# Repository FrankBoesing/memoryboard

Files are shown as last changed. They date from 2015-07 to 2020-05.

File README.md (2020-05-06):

# Memoryboard for Teensy 3.x

1..6x spi jedec-memory soic-8 (e.g. 23LC1024 RAM)

Top
Bottom

Partslist:

- 6 x SPI jedec Memory of your choice* (SOIC-8) (RAM (e.g. 23LC1024) , Flash...)
- 1 x 74LCX126MX SOIC-14
- 1 x 74LCX138MX SOIC-16
- 6 x Capacitor 0.1uF 0603
- 3 x Resistor 10K 0603

*Check package-width!

https://forum.pjrc.com/threads/29276-Limits-of-delay-effect-in-audio-library
(up to 9 sec. delay for audio 44kHz)

Of course, this board is not only for the audio-library! 

OSH-Park shared project:
https://oshpark.com/shared_projects/KZt5PaU7

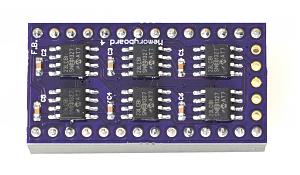
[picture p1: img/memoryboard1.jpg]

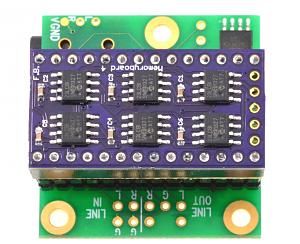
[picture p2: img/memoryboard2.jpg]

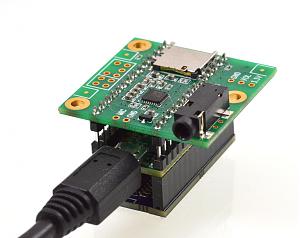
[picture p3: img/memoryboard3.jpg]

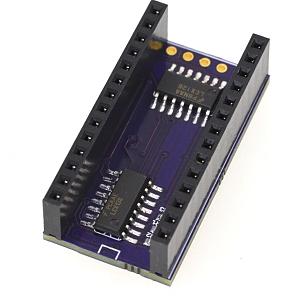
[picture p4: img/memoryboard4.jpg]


Video of delay effect:
video (https://www.youtube.com/watch?v=d80d1HWy5_s)

Pins used:
- 3v3, 
- GND, 
- 2,3,4 (Chipselects) 
- 7, 12, 14 (SPI)

### License

<br />This work is licensed under a <a rel="license" href="http://creativecommons.org/licenses/by-sa/4.0/">Creative Commons Attribution-ShareAlike 4.0 International License</a>.

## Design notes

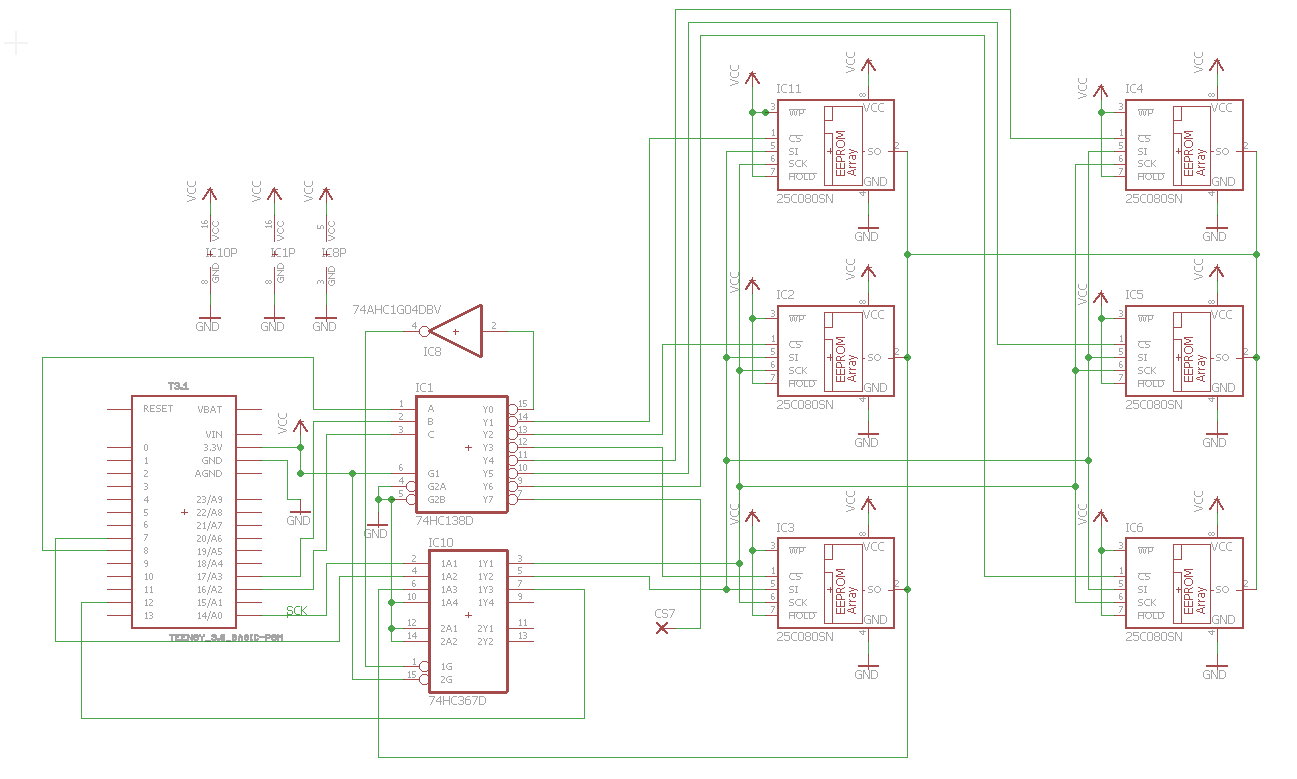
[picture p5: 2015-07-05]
memoryboard-schematic.png

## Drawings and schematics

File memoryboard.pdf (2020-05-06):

# SPI Memory VCC

# SPI Memory VCC

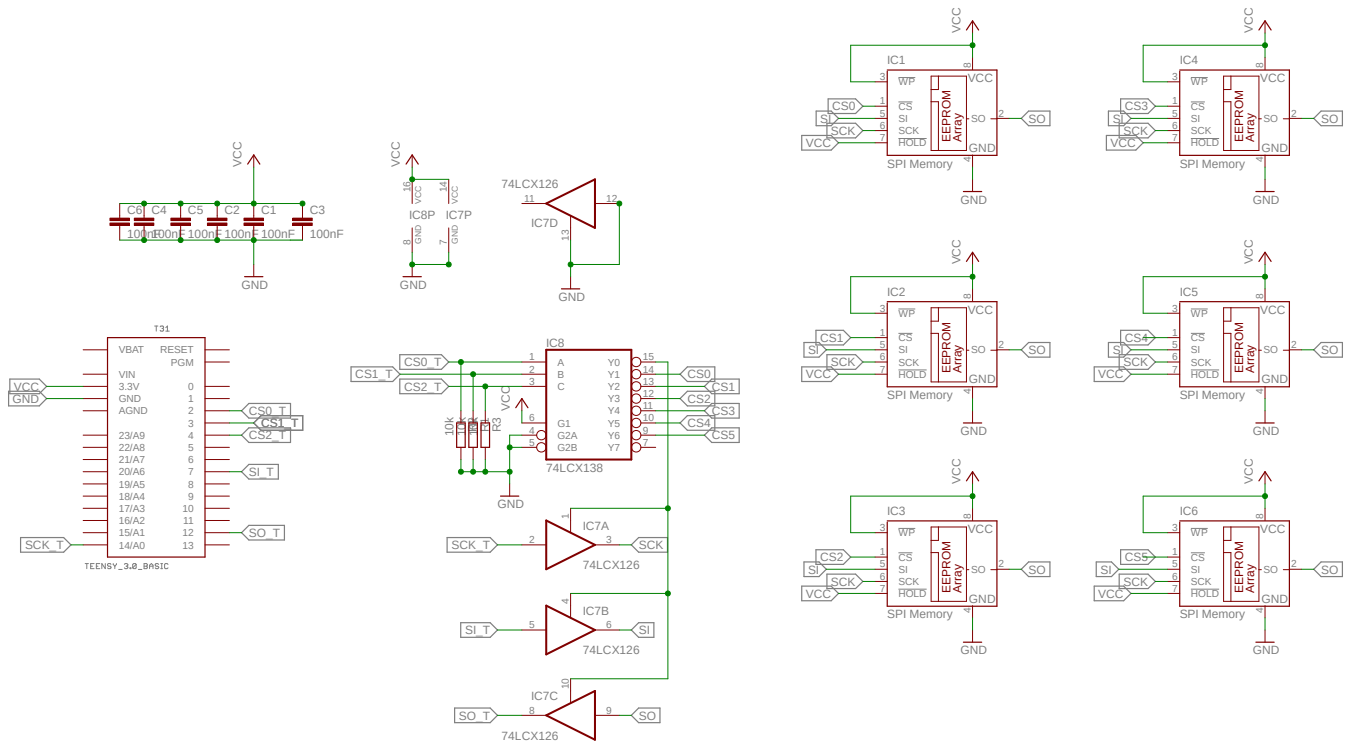
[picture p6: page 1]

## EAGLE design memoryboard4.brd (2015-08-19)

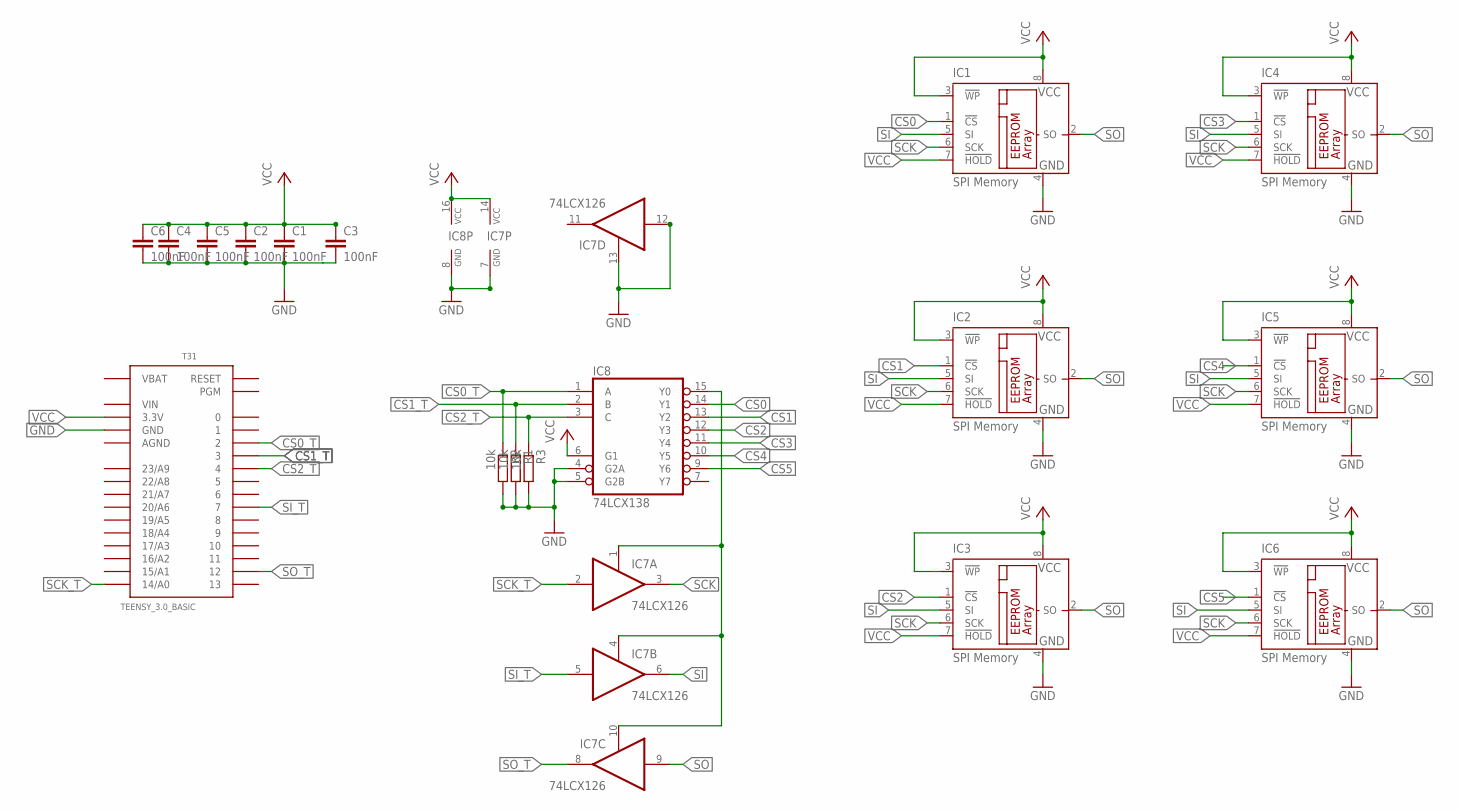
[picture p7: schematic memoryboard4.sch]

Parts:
C1, C2, C3, C4, C5, C6: 100nF; C0603
IC1, IC2, IC3, IC4, IC5, IC6: SPI Memory; SO-08
IC7: 74LCX126; SO14
IC8: 74LCX138; SO16
R1, R2, R3: 10k; R0603
T31: TEENSY_3.0_BASIC

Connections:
AGND: T31.AGND
CS0: IC1.1 (!CS), IC8.14 (Y1)
CS0_T: IC8.1 (A), R2.1, T31.2
CS1: IC2.1 (!CS), IC8.13 (Y2)
CS1_T: IC8.2 (B), R1.1, T31.3
CS2: IC3.1 (!CS), IC8.12 (Y3)
CS2_T: IC8.3 (C), R3.1, T31.4
CS3: IC4.1 (!CS), IC8.11 (Y4)
CS4: IC5.1 (!CS), IC8.10 (Y5)
CS5: IC6.1 (!CS), IC8.9 (Y6)
GND: C1.2, C2.2, C3.2, C4.2, C5.2, C6.2, IC1.4 (GND), IC2.4 (GND), IC3.4 (GND), IC4.4 (GND), IC5.4 (GND), IC6.4 (GND), IC7.7 (GND), IC7.12 (I), IC7.13 (OE), IC8.4 (G2A), IC8.5 (G2B), IC8.8 (GND), R1.2, R2.2, R3.2, T31.GND, T31.GND1 (GND)
SCK: IC1.6 (SCK), IC2.6 (SCK), IC3.6 (SCK), IC4.6 (SCK), IC5.6 (SCK), IC6.6 (SCK), IC7.3 (O)
SCK_T: IC7.2 (I), T31.14/A0
SI: IC1.5 (SI), IC2.5 (SI), IC3.5 (SI), IC4.5 (SI), IC5.5 (SI), IC6.5 (SI), IC7.6 (O)
SI_T: IC7.5 (I), T31.7
SO: IC1.2 (SO), IC2.2 (SO), IC3.2 (SO), IC4.2 (SO), IC5.2 (SO), IC6.2 (SO), IC7.9 (I)
SO_T: IC7.8 (O), T31.12
SPI_ENABLE: IC7.1 (OE), IC7.4 (OE), IC7.10 (OE), IC8.15 (Y0)
VBAT: T31.VBAT
VCC: C1.1, C2.1, C3.1, C4.1, C5.1, C6.1, IC1.3 (!WP), IC1.7 (!HOLD), IC1.8 (VCC), IC2.3 (!WP), IC2.7 (!HOLD), IC2.8 (VCC), IC3.3 (!WP), IC3.7 (!HOLD), IC3.8 (VCC), IC4.3 (!WP), IC4.7 (!HOLD), IC4.8 (VCC), IC5.3 (!WP), IC5.7 (!HOLD), IC5.8 (VCC), IC6.3 (!WP), IC6.7 (!HOLD), IC6.8 (VCC), IC7.14 (VCC), IC8.6 (G1), IC8.16 (VCC), T31.3.3V, T31.3.3V1 (3.3V)
VIN: T31.VIN

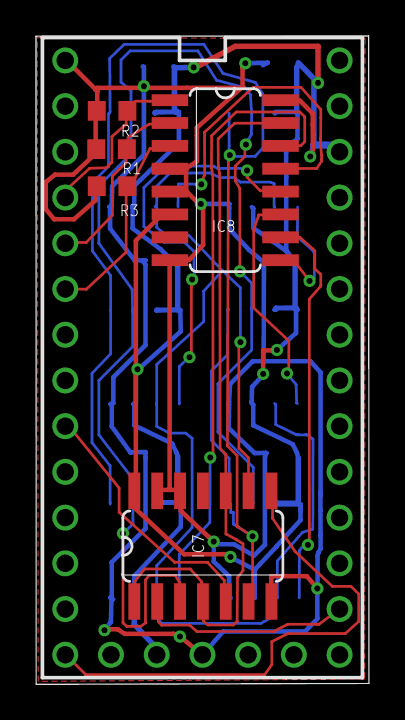
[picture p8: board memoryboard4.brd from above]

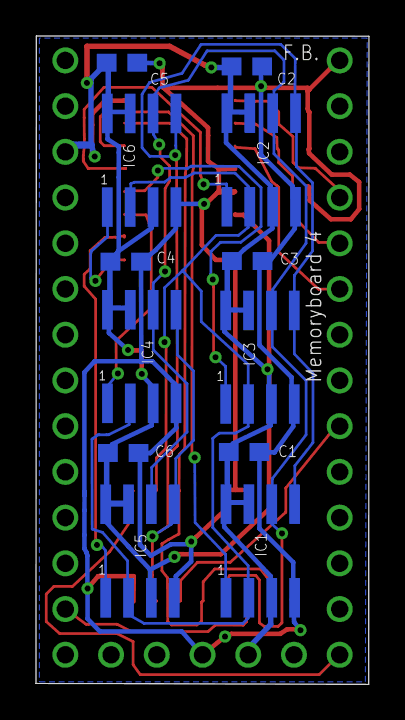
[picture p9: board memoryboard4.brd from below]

Board: 2 copper layers, 18.5 x 36.0 mm, 18 parts (12 on the bottom side), 18 nets.

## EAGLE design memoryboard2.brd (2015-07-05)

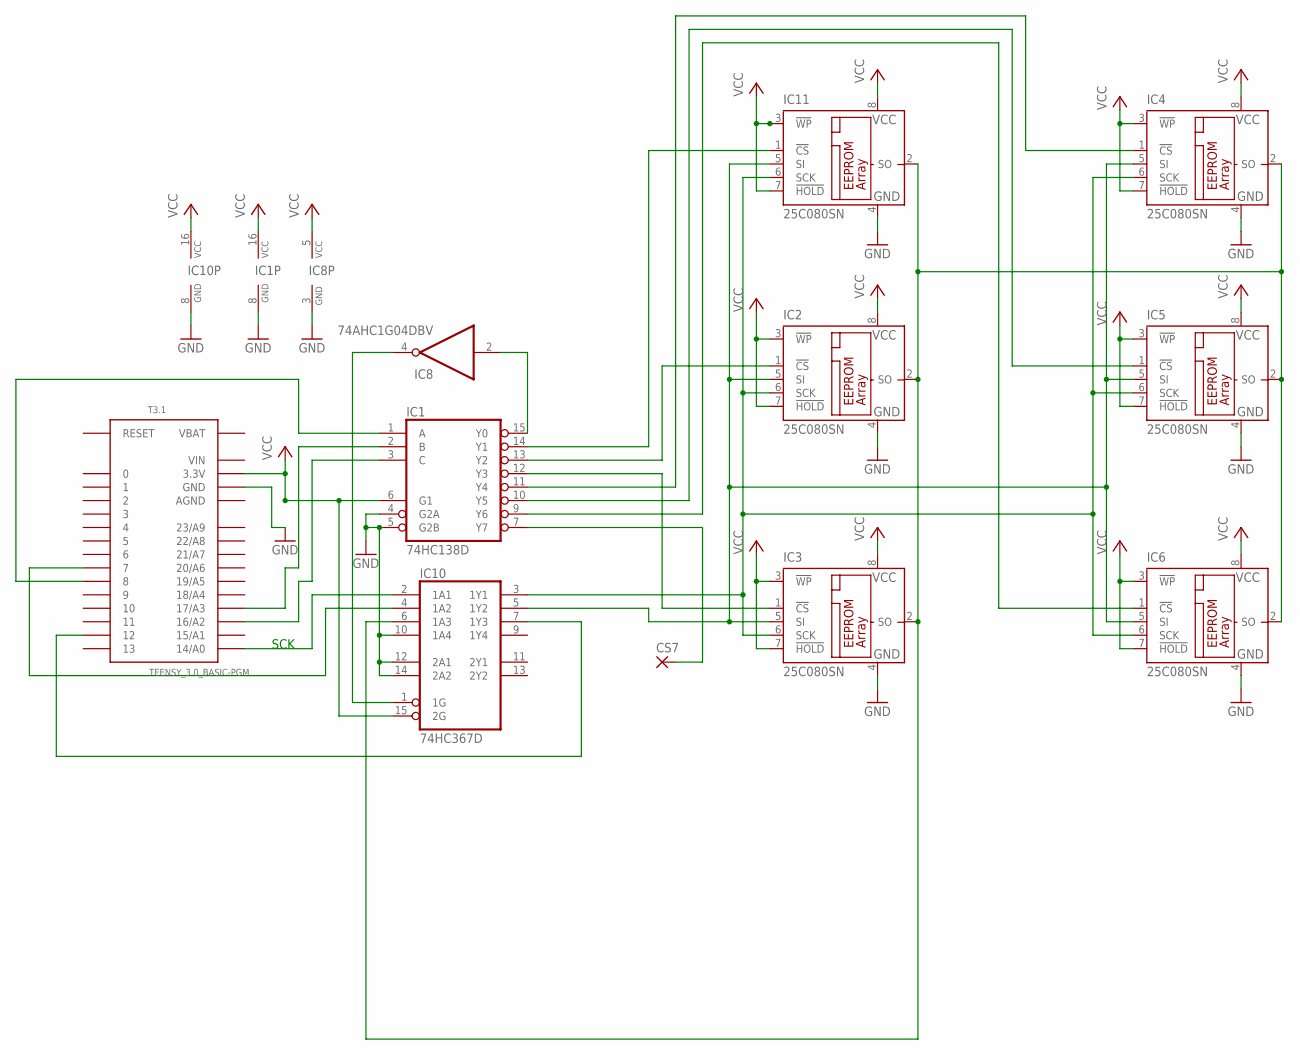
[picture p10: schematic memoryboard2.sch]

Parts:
CS7: SMD2; SMD1,27-2,54
IC1: 74HC138D; SO16
IC2, IC3, IC4, IC5, IC6, IC11: 25C080SN; SO-08
IC8: 74AHC1G04DBV; SOT23-5
IC10: 74HC367D; SO16
T3.1: TEENSY_3.0_BASIC-PGM

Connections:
AGND: T3.1.AGND
GND: IC1.4 (G2A), IC1.5 (G2B), IC1.8 (GND), IC2.4 (GND), IC3.4 (GND), IC4.4 (GND), IC5.4 (GND), IC6.4 (GND), IC8.3 (GND), IC10.8 (GND), IC10.10 (1A4), IC10.12 (2A1), IC10.14 (2A2), IC11.4 (GND), T3.1.GND, T3.1.GND1 (GND)
unnamed: IC8.4 (O), IC10.1 (1G)
unnamed: IC10.2 (1A1), T3.1.14/A0
unnamed: IC10.4 (1A2), T3.1.7
unnamed: IC10.7 (1Y3), T3.1.12
unnamed: IC1.15 (Y0), IC8.2 (I)
unnamed: IC1.3 (C), T3.1.16/A2
unnamed: CS7.1, IC1.7 (Y7)
unnamed: IC1.10 (Y5), IC5.1 (!CS)
unnamed: IC2.6 (SCK), IC3.6 (SCK), IC4.6 (SCK), IC5.6 (SCK), IC6.6 (SCK), IC10.3 (1Y1), IC11.6 (SCK)
unnamed: IC1.2 (B), T3.1.17/A3
unnamed: IC1.9 (Y6), IC6.1 (!CS)
unnamed: IC1.12 (Y3), IC3.1 (!CS)
unnamed: IC2.2 (SO), IC3.2 (SO), IC4.2 (SO), IC5.2 (SO), IC6.2 (SO), IC10.6 (1A3), IC11.2 (SO)
unnamed: IC1.11 (Y4), IC4.1 (!CS)
unnamed: IC1.1 (A), T3.1.8
unnamed: IC2.5 (SI), IC3.5 (SI), IC4.5 (SI), IC5.5 (SI), IC6.5 (SI), IC10.5 (1Y2), IC11.5 (SI)
unnamed: IC1.14 (Y1), IC11.1 (!CS)
unnamed: IC1.13 (Y2), IC2.1 (!CS)
VBAT: T3.1.VBAT
VCC: IC1.6 (G1), IC1.16 (VCC), IC2.3 (!WP), IC2.7 (!HOLD), IC2.8 (VCC), IC3.3 (!WP), IC3.7 (!HOLD), IC3.8 (VCC), IC4.3 (!WP), IC4.7 (!HOLD), IC4.8 (VCC), IC5.3 (!WP), IC5.7 (!HOLD), IC5.8 (VCC), IC6.3 (!WP), IC6.7 (!HOLD), IC6.8 (VCC), IC8.5 (VCC), IC10.15 (2G), IC10.16 (VCC), IC11.3 (!WP), IC11.7 (!HOLD), IC11.8 (VCC), T3.1.3.3V, T3.1.3.3V1 (3.3V)
VIN: T3.1.VIN

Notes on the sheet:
SCK

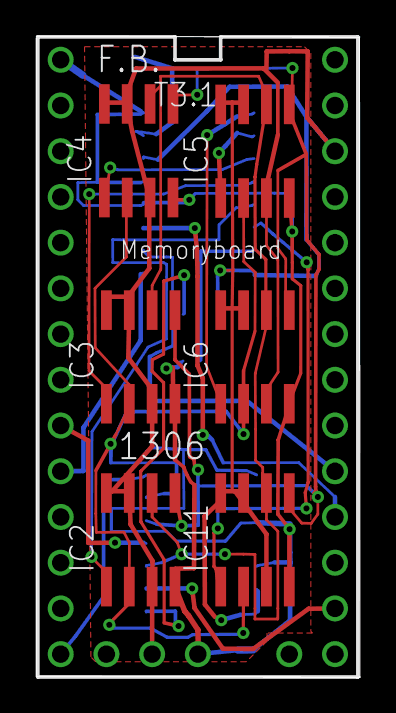
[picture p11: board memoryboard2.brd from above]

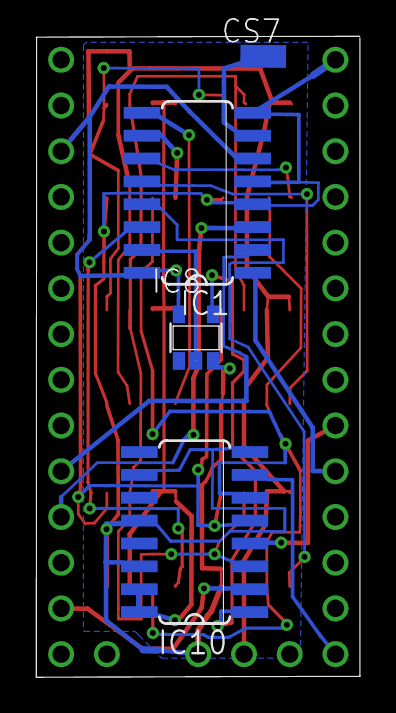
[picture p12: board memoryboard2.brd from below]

Board: 2 copper layers, 18.0 x 35.6 mm, 11 parts (4 on the bottom side), 20 nets.

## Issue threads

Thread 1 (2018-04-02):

OK to swap the 100nF caps for 4.7uF?

dturner, 2018-04-02:
Hi Frank. Thanks for sharing this awesome little board design. A quick question if you don't mind. I accidentally used 4.7uF capacitors instead of 100nF. The test script runs successfully but I'm wondering whether I should swap them for 100nF?

FrankBoesing, 2018-04-02:
Hi Don, the capacitors are meant as blocking caps for the RAMs- their value is not that important I think - but 4.7uF is really a lot more than in the datasheet. On the other hand, if it works...

dturner, 2018-04-02:
OK thanks Frank, I'll leave as is. If the RAM chips blow up I'll update this ticket :)

Closed 2018-04-02.

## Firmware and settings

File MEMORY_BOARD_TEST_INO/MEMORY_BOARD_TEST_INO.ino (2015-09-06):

/* Memoryboard code is placed under the MIT license
 * Copyright (c) 2015 Frank Bösing
 *
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
 * THE SOFTWARE IS PROVIDED "AS IS", WITHOUT WARRANTY OF ANY KIND,
 * EXPRESS OR IMPLIED, INCLUDING BUT NOT LIMITED TO THE WARRANTIES OF
 * MERCHANTABILITY, FITNESS FOR A PARTICULAR PURPOSE AND
 * NONINFRINGEMENT. IN NO EVENT SHALL THE AUTHORS OR COPYRIGHT HOLDERS
 * BE LIABLE FOR ANY CLAIM, DAMAGES OR OTHER LIABILITY, WHETHER IN AN
 * ACTION OF CONTRACT, TORT OR OTHERWISE, ARISING FROM, OUT OF OR IN
 * CONNECTION WITH THE SOFTWARE OR THE USE OR OTHER DEALINGS IN THE
 * SOFTWARE.
 */

 #include <SPI.h>
#include <SPIFIFO.h>
#include <arm_math.h>
#include <kinetis.h>
#include "memoryboard.h"


#define BUFSIZE 8000
#define BUFSIZE3 1024

DMAMEM uint8_t buf1[BUFSIZE];
DMAMEM uint8_t buf2[BUFSIZE];
DMAMEM uint16_t buf3[BUFSIZE3];

uint32_t laufnr;


void setup() {
 memoryboard_init();
 while(!Serial);
 Serial.println("Start");
 laufnr = 0;
}


void checkMem(int num){
int m,res;
uint32_t addr;

  Serial.printf("RAM #%d ... ", num);
  m = millis();
  res = 0;
  if (ram_readRDMR(num) != 0x40) {
	  res = 1;
  }
  for (addr = 0; addr < 128*1024; addr += BUFSIZE) {
  //for (addr = 0; addr < BUFSIZE; addr += BUFSIZE) {
  if (res == 0) {
    memset(buf1,0x55,BUFSIZE);
    ram_write(num, buf1, addr, BUFSIZE);
    ram_read(num, buf2, addr, BUFSIZE);
    res = memcmp(buf1,buf2,BUFSIZE);
  }
  if (res==0) {
    memset(buf1,0xaa,BUFSIZE);
    ram_write(num, buf1, addr, BUFSIZE);
    ram_read(num, buf2, addr, BUFSIZE);
    res = memcmp(buf1,buf2,BUFSIZE);
  }
  if (res==0) {
    memset(buf1,0x00,BUFSIZE);
    ram_write(num, buf1, addr, BUFSIZE);
    ram_read(num, buf2, addr, BUFSIZE);
    res = memcmp(buf1,buf2,BUFSIZE);
  }
/*
  if (res==0) {
    memset(buf1,0xff,BUFSIZE);
    ram_write(num, buf1, addr, BUFSIZE);
    ram_read(num, buf2, addr, BUFSIZE);
    res = memcmp(buf1,buf2,BUFSIZE);
  }
*/
  if (res==0) {
    int i;
    for (i=0; i< BUFSIZE3; i++)
      buf3[i] = i;
    ram_write(num, (uint8_t*)&buf3, addr, BUFSIZE);
    ram_read(num, buf2, addr, BUFSIZE3*2);
    res = memcmp(buf3,buf2,BUFSIZE3);
  }
  }
  m = millis()-m;
  Serial.printf("%s %ums\r\n",res==0?"OK":"ERROR",m);
  if (res) {
	Serial.printf("Stop.\r\nDump:\r\n");
	for (int i=0; i<BUFSIZE; i++)
		Serial.printf("0x%x<->0x%x\r\n", buf1[i], buf2[i]);
    while(1) {;}
  }

}


void loop() {
int num;
  laufnr++;
  Serial.printf("Run %u:\r\n", laufnr);

  for (num=1; num <=RAM_NUM_CHIPS; num++) checkMem(num);
  Serial.println();
  delay(300);
}

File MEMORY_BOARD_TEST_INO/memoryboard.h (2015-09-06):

/* Memoryboard library code is placed under the MIT license
 * Copyright (c) 2015 Frank Bösing
 *
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
 * THE SOFTWARE IS PROVIDED "AS IS", WITHOUT WARRANTY OF ANY KIND,
 * EXPRESS OR IMPLIED, INCLUDING BUT NOT LIMITED TO THE WARRANTIES OF
 * MERCHANTABILITY, FITNESS FOR A PARTICULAR PURPOSE AND
 * NONINFRINGEMENT. IN NO EVENT SHALL THE AUTHORS OR COPYRIGHT HOLDERS
 * BE LIABLE FOR ANY CLAIM, DAMAGES OR OTHER LIABILITY, WHETHER IN AN
 * ACTION OF CONTRACT, TORT OR OTHERWISE, ARISING FROM, OUT OF OR IN
 * CONNECTION WITH THE SOFTWARE OR THE USE OR OTHER DEALINGS IN THE
 * SOFTWARE.
 */

// Currently 23LC1024 SPI RAM only!

#ifndef _memoryboard_h
#define _memoryboard_h

/**************************/
// Edit here:

#define MEMORYBOARD_VERSION 3
#define RAM_NUM_CHIPS         (4) //# of RAMs

//End "Edit here"
/**************************/

#include <SPI.h>
//#include <SPIFIFO.h>
#include <DMAChannel.h>
#include <arm_math.h>

#if (MEMORYBOARD_VERSION < 4)
#define MEMORYBOARD_CS0     8
#define MEMORYBOARD_CS1    17
#define MEMORYBOARD_CS2    16
#elif (MEMORYBOARD_VERSION == 4)
#define MEMORYBOARD_CS0     2
#define MEMORYBOARD_CS1     3
#define MEMORYBOARD_CS2     4
#else
#error unknown MEMORYBOARD_VERSION
#endif

#define RAM_CHIP_SIZE         (128*1024) //Size per RAM
#define RAM_SIZE              (RAM_CHIP_SIZE * RAM_NUM_CHIPS)
#define RAM_CHIP_SIZE_MASK    (RAM_CHIP_SIZE - 1)
#define RAM_SIZE_MASK         (RAM_SIZE - 1)


#define MEMORYBOARD_SPICONFIG SPISettings(20000000, MSBFIRST, SPI_MODE0 ) //Speed. 23LC1024 = 20MHz max, see Datasheet.
#define MEMORYBOARD_SCK   	14
#define MEMORYBOARD_MOSI   	 7
#define MEMORYBOARD_MISO  	12

//RAM-Instructions
#define RAM_INSTR_READ      0x03
#define RAM_INSTR_WRITE     0x02
#define RAM_INSTR_EDIO      0x3B
#define RAM_INSTR_EQIO      0x38
#define RAM_INSTR_RSTIO     0xFF
#define RAM_INSTR_RDMR      0x05
#define RAM_INSTR_WRMR      0x01

#define RAM_BYTEMODE        0x00
#define RAM_PAGEMODE        0x80
#define RAM_SEQUENTIALMODE  0x40

#if (RAM_NUM_CHIPS < 0) || (RAM_NUM_CHIPS > 6)
#error please check RAM_NUM_CHIPS
#endif

#define MEMORYBOARD_PINMODE0	  pinMode(MEMORYBOARD_CS0, OUTPUT)
#define MEMORYBOARD_PINMODE1
#define MEMORYBOARD_PINMODE2
#define MEMORYBOARD_SETCS0(state) digitalWriteFast(MEMORYBOARD_CS0, state)
#define MEMORYBOARD_SETCS1(state)
#define MEMORYBOARD_SETCS2(state)
#if RAM_NUM_CHIPS > 1
#undef MEMORYBOARD_PINMODE1
#undef MEMORYBOARD_SETCS1
#define MEMORYBOARD_PINMODE1	  pinMode(MEMORYBOARD_CS1, OUTPUT)
#define MEMORYBOARD_SETCS1(state) digitalWriteFast(MEMORYBOARD_CS1, state)
#endif
#if RAM_NUM_CHIPS > 3
#undef MEMORYBOARD_PINMODE2
#undef MEMORYBOARD_SETCS2
#define MEMORYBOARD_PINMODE2	  {pinMode(MEMORYBOARD_CS2, OUTPUT);}
#define MEMORYBOARD_SETCS2(state) digitalWriteFast(MEMORYBOARD_CS2, state)
#endif

#define CSRELEASE				MEMORYBOARD_SETCS0(LOW);MEMORYBOARD_SETCS1(LOW);MEMORYBOARD_SETCS2(LOW)

static DMAChannel dmatx(true);
static DMAChannel dmarx(true);
static DMAMEM uint8_t dummy;
static volatile bool done;

static inline
void csassert(const int cs)
{
  switch(cs) {
    default:{ CSRELEASE;  break; }
    case 1: { MEMORYBOARD_SETCS0(HIGH); MEMORYBOARD_SETCS1(LOW);  MEMORYBOARD_SETCS2(LOW);  break; }
#if RAM_NUM_CHIPS > 1
    case 2: { MEMORYBOARD_SETCS0(LOW);  MEMORYBOARD_SETCS1(HIGH); MEMORYBOARD_SETCS2(LOW);  break; }
#if RAM_NUM_CHIPS > 2
    case 3: { MEMORYBOARD_SETCS0(HIGH); MEMORYBOARD_SETCS1(HIGH); MEMORYBOARD_SETCS2(LOW);  break; }
#if RAM_NUM_CHIPS > 3
    case 4: { MEMORYBOARD_SETCS0(LOW);  MEMORYBOARD_SETCS1(LOW);  MEMORYBOARD_SETCS2(HIGH); break; }
#if RAM_NUM_CHIPS > 4
    case 5: { MEMORYBOARD_SETCS0(HIGH); MEMORYBOARD_SETCS1(LOW);  MEMORYBOARD_SETCS2(HIGH); break; }
#if RAM_NUM_CHIPS > 5
    case 6: { MEMORYBOARD_SETCS0(LOW);  MEMORYBOARD_SETCS1(HIGH); MEMORYBOARD_SETCS2(HIGH); break; }
#if RAM_NUM_CHIPS > 6	
    case 7: { MEMORYBOARD_SETCS0(HIGH); MEMORYBOARD_SETCS1(HIGH); MEMORYBOARD_SETCS2(HIGH); break; }
#endif  
#endif
#endif
#endif
#endif
#endif
  }
}

static inline
void ram_stop(void)
{
	CSRELEASE;
	SPI.endTransaction();
}

//Read Mode Register
int ram_readRDMR(const int RamNo)
{
	int ret;
	SPI.beginTransaction(MEMORYBOARD_SPICONFIG);
	csassert(RamNo);
	SPI.transfer(RAM_INSTR_RDMR);
	ret = SPI.transfer(0);
	ram_stop();
	return ret;
}

//Write Mode Register
void ram_writeRDMR(uint8_t mode, const int RamNo)
{
	SPI.beginTransaction(MEMORYBOARD_SPICONFIG);
	csassert(RamNo);
	SPI.transfer16(RAM_INSTR_WRMR << 8 | mode);
	ram_stop();
}


static inline
void ram_startRead(const uint8_t cs, const uint32_t addr)
{
	uint32_t tmp;
	SPI.beginTransaction(MEMORYBOARD_SPICONFIG);
	csassert(cs);
	tmp = (RAM_INSTR_READ << 24) | (addr & RAM_CHIP_SIZE_MASK);
	SPI.transfer16( tmp>>16 );
	SPI.transfer16( tmp );
}
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

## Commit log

2015-07-05 schematic png
2015-07-08 New Revision
    [memoryboard2.brd, memoryboard2.sch, memoryboard3.brd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]
2015-07-13 new revision, more capacitors, added led
    [memoryboard2.brd, memoryboard2.sch, memoryboard3.brd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]
2015-08-02 Add Testsoftware for RAMs
    [memoryboard2.brd, memoryboard2.sch]
2015-08-19 Update "Memoryboard 4"
    [memoryboard3.brd, memoryboard3.sch, memoryboard31.brd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]
2015-09-06 improved DMA, rmv need of DmaSpi
